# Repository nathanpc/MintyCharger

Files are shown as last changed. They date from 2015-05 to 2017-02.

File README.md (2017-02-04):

# MintyCharger

A very simple 9V (9.6V and 8.4V) NiMH charger based on a PIC microcontroller with a charge state indicator that fits neatly inside a Altoids tin.

## Schematic and Board Layout

A very simple topology, the PIC is generating a PWM pulse which is converted to a analog voltage by using a filter, which is fed into a op-amp that will be controlling the voltage. The current limit is set by the potentiometer `R10`. This is literally a miniature version of a primitive "lab" power supply.

Schematic

As you can see the board is very tiny and is designed to fit inside a Altoids tin along side the battery that it will be charging.

Board Layout

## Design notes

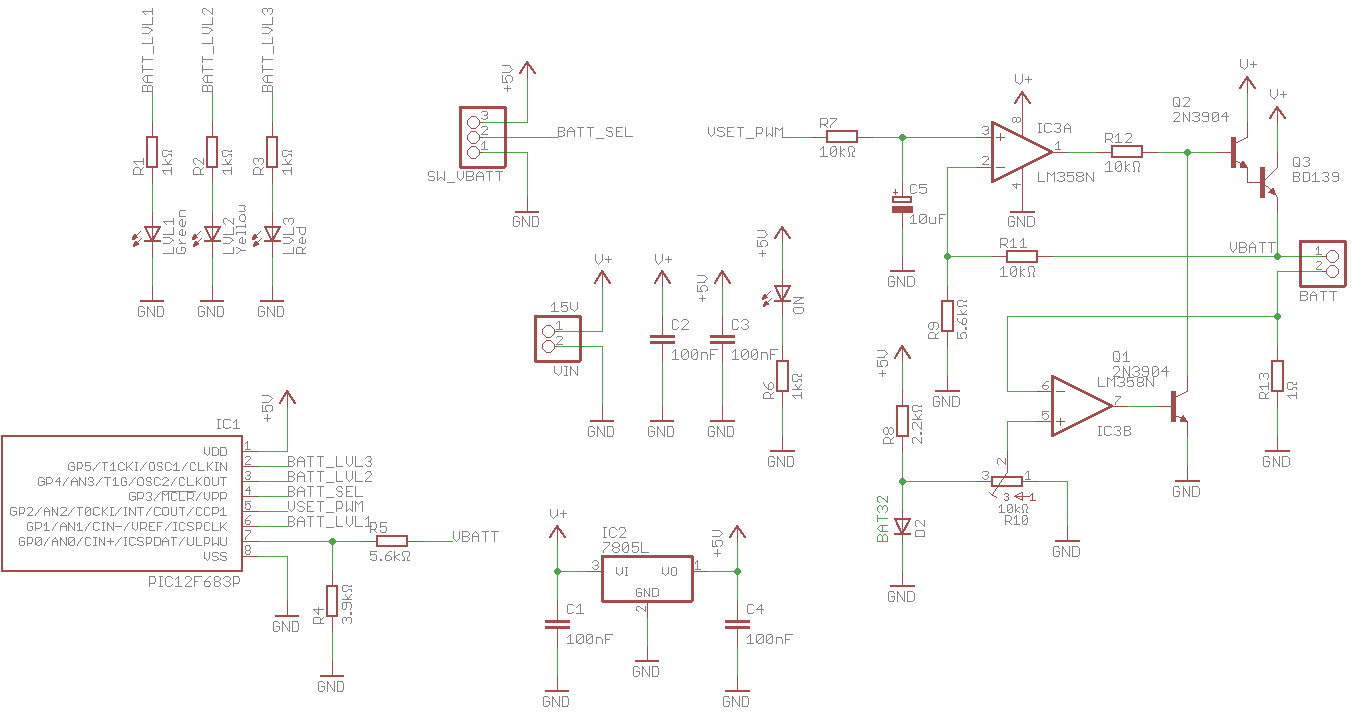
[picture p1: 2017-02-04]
images/Schematic (Rev A).png

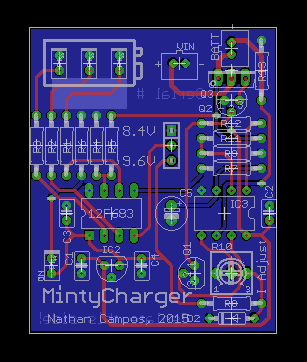
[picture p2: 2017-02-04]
images/Board (Rev A).png

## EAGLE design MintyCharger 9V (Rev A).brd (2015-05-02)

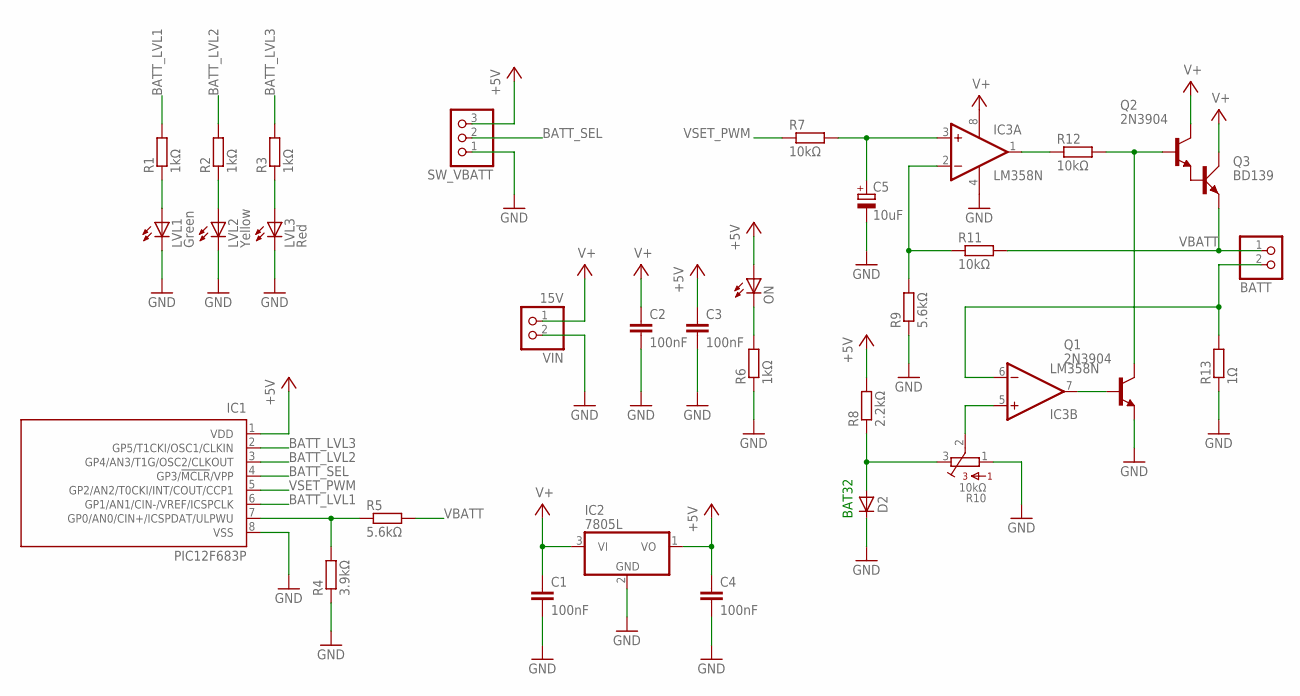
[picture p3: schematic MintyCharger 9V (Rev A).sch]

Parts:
BATT: JST_2PIN-THM; JST-PH-2-THM
C1, C2, C3, C4: 100nF; C025-025X050
C5: 10uF; E2,5-6
D2: 1N4148DO35-7; DO35-7
IC1: PIC12F683P; DIL8
IC2: 7805L; TO92
IC3: LM358N; DIL08
LVL1: Green; LED2X5
LVL2: Yellow; LED2X5
LVL3: Red; LED2X5
ON: LEDSQR2X5; LED2X5
Q1, Q2: 2N3904; TO92
Q3: BD139; TO126AV
R1, R2, R3, R6: 1kΩ; 0207/10
R4: 3.9kΩ; 0207/10
R5, R9: 5.6kΩ; 0207/10
R7, R11, R12: 10kΩ; 0207/10
R8: 2.2kΩ; 0207/10
R10: 10kΩ; 3362U
R13: 1Ω; 0207/10
SW_VBATT: PINHD-1X3; 1X03
VIN: 15V; JST-PH-2-THM

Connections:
+5V: C3.1, C4.1, IC1.1 (VDD), IC2.1 (VO), ON.A, R8.2, SW_VBATT.3
BATT_LVL1: IC1.6 (GP1/AN1/CIN-/VREF/ICSPCLK), R1.2
BATT_LVL2: IC1.3 (GP4/AN3/T1G/OSC2/CLKOUT), R2.2
BATT_LVL3: IC1.2 (GP5/T1CKI/OSC1/CLKIN), R3.2
BATT_SEL: IC1.4 (GP3/!MCLR!/VPP), SW_VBATT.2
GND: C1.2, C2.2, C3.2, C4.2, C5.-, D2.C, IC1.8 (VSS), IC2.2 (GND), IC3.4 (V-), LVL1.K (C), LVL2.K (C), LVL3.K (C), Q1.3 (E), R4.1, R6.1, R9.1, R10.1, R13.1, SW_VBATT.1, VIN.2 (1)
ISENSE: BATT.2 (1), IC3.6 (-IN), R13.2
unnamed: LVL1.A, R1.1
unnamed: IC3.2 (-IN), R9.2, R11.1
unnamed: IC3.1 (OUT), R12.1
unnamed: Q2.3 (E), Q3.B
unnamed: Q1.1 (C), Q2.2 (B), R12.2
unnamed: IC3.7 (OUT), Q1.2 (B)
unnamed: D2.A, R8.1, R10.3
unnamed: IC3.5 (+IN), R10.2
unnamed: IC1.7 (GP0/AN0/CIN+/ICSPDAT/ULPWU), R4.2, R5.1
unnamed: LVL2.A, R2.1
unnamed: LVL3.A, R3.1
unnamed: ON.K (C), R6.2
V+: C1.1, C2.1, IC2.3 (VI), IC3.8 (V+), Q2.1 (C), Q3.C, VIN.1 (2)
VBATT: BATT.1 (2), Q3.E, R5.2, R11.2
VOUT: C5.+, IC3.3 (+IN), R7.2
VSET_PWM: IC1.5 (GP2/AN2/T0CKI/INT/COUT/CCP1), R7.1

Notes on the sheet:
BAT32

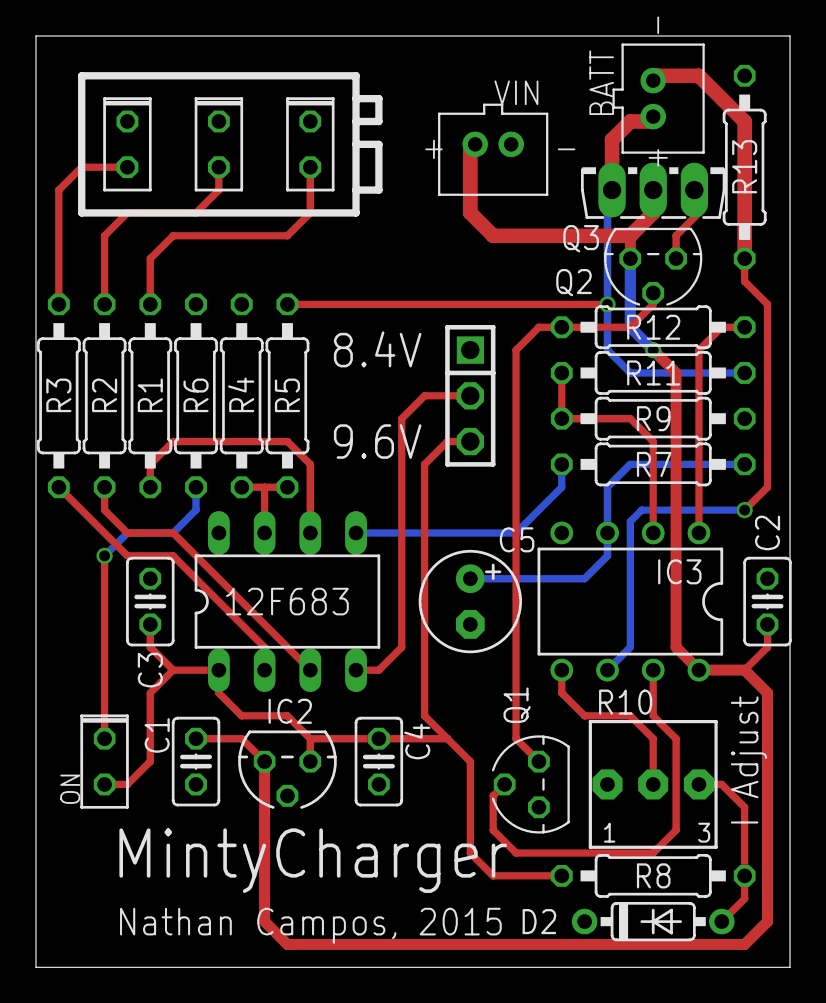
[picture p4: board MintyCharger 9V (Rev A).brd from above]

Board: 4 copper layers, 41.9 x 51.7 mm, 32 parts (0 on the bottom side), 23 nets.

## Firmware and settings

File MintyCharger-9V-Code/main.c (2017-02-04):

/*
 * File:   main.c
 * Author: nathanpc
 *
 * Created on April 30, 2015, 6:51 PM
 */


#include <xc.h>
#include <pic12f683.h>
#include <stdint.h>

#pragma config MCLRE = OFF, CP = OFF, CPD = OFF, BOREN = OFF, WDTE = OFF
#pragma config PWRTE = OFF, FOSC = INTOSCIO

#define _XTAL_FREQ 4000000
#define HIGH 1
#define LOW  0
#define DEADCELL 1
#define _8V4 0
#define _9V6 1

void set_voltage(uint8_t type);
void battery_indicator(unsigned int voltage);

void main() {
    TRISIO = 0b000000;
    ANSEL = 0;

    uint8_t sGPIO = 0;

    // Setup the pins.
    TRISIO = 0b001001;

    // Setup ADC.
    ANSELbits.ADCS = 0b001;  // Fosc / 8 = 2.0us (4MHz clock).
    ANSELbits.ANS = 0b0001;  // Enable AN0.
    ADCON0bits.ADFM = 1;     // LSB of result in ADRESH<7>
    ADCON0bits.VCFG = 0;     // Voltage reference set to Vdd.
    ADCON0bits.CHS = 0b00;   // Select channel AN0.
    ADCON0bits.ADON = 1;     // Turn ADC ON.

    // Initialize the PWM module.
    T2CONbits.T2CKPS = 0b00;     // Timer2 Prescaler = 1.
    T2CONbits.TMR2ON = 1;        // Enable Timer2.
                                 // Timer2 will increment every 1us with 4MHz.
    PR2 = 49;                    // Period = 50 * 1us = 50us or 20kHz.
    CCP1CONbits.CCP1M = 0b1100;  // Single output active high PWM.
    set_voltage(GPIObits.GP3);

    unsigned int res = 0;
    unsigned int res2 = 0;

    while (1) {
        // Check if the switch changed.
        /*if (GPIObits.GP3 != sGP3) {
            sGP3 = GPIObits.GP3;
            set_voltage(sGP3);
        }*/

        __delay_us(10);  // Acquisition delay.
        ADCON0bits.GO = 1;
        while (ADCON0bits.nDONE)
            ;
        res = (ADRESH << 8) | ADRESL;
        res2 = res / 5;//(res - 70) / 2;
        CCP1CONbits.DC1B = res2 & 0b0000000011;
        CCPR1L = res2 >> 2;

        battery_indicator(res);
    }
}

/**
 * Sets the PWM duty cycle according to the voltage selection switch.
 *
 * @param type Voltage selection switch position.
 */
void set_voltage(uint8_t type) {
    if (type == _8V4) {
        // 75%
        CCP1CONbits.DC1B  = 0b11;
        CCPR1L = 0b100101;
    } else {
        // 86%
        CCP1CONbits.DC1B  = 0b10;
        CCPR1L = 0b101011;
    }
}

void calibrate() {
    // TODO: Implement a calibration mode to fix the imperfections in the feedback
    //       resistors. Enter the mode by shorting the battery terminals (ADC will
    //       read 0), then flash the LEDs in a pattern so the user can unshort,
    //       then read the voltages.
}

void battery_indicator(unsigned int voltage) {
    // Vbatt < 8.2V
    if (voltage < 689) {
        if (voltage <= 614) {
            // Vbatt < 7.3V
            GPIO = 0b000010;
            __delay_ms(600);
            GPIO = 0b000000;
            __delay_ms(600);
        } else if (voltage <= 639) {
            // Vbatt < 7.6V
            GPIO = 0b000010;
            __delay_ms(400);
            GPIO = 0b000000;
            __delay_ms(400);
        } else if (voltage <= 664) {
            // Vbatt < 7.9V
            GPIO = 0b000010;
            __delay_ms(200);
            GPIO = 0b000000;
            __delay_ms(200);
        } else {
            // Vbatt < 8.2V
            GPIO = 0b000010;
            __delay_ms(100);
            GPIO = 0b000000;
            __delay_ms(100);
        }
    }

    // Vbatt < 9.4V
    if (voltage < 790 && voltage > 689) {
        if (voltage <= 715) {
            // Vbatt < 8.5V
            GPIO = 0b000010;
            __delay_ms(600);
            GPIO = 0b000010;
            __delay_ms(600);
        } else if (voltage <= 740) {
            // Vbatt < 8.8V
            GPIO = 0b010010;
            __delay_ms(400);
            GPIO = 0b000010;
            __delay_ms(400);
        } else if (voltage <= 765) {
            // Vbatt < 9.1V
            GPIO = 0b010010;
            __delay_ms(200);
            GPIO = 0b000010;
            __delay_ms(200);
        } else {
            // Vbatt < 9.4V
            GPIO = 0b010010;
            __delay_ms(100);
            GPIO = 0b000010;
            __delay_ms(100);
        }
    }

    // Vbatt < 10.5V
    if (voltage > 790) {
        if (voltage <= 816) {
            // Vbatt < 9.7V
            GPIO = 0b110010;
            __delay_ms(600);
            GPIO = 0b010010;
            __delay_ms(600);
        } else if (voltage <= 841) {
            // Vbatt < 10.0V
            GPIO = 0b110010;
            __delay_ms(400);
            GPIO = 0b010010;
            __delay_ms(400);
        } else if (voltage <= 866) {
            // Vbatt < 10.3V
            GPIO = 0b110010;
            __delay_ms(200);
            GPIO = 0b010010;
            __delay_ms(200);
        } else if (voltage <= 880) {
            // Vbatt < 10.5V
            GPIO = 0b110010;
            __delay_ms(100);
            GPIO = 0b010010;
            __delay_ms(100);
        } else {
            GPIO = 0b110010;
        }
    }

    // TODO: Implement 9.6V battery.
}
